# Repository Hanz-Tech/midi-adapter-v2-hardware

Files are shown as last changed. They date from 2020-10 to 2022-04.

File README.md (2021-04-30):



Buy it Here 



[Etsy](https://www.etsy.com/ca/HanzTechInc/listing/979132858/pocket-operator-midi-adapter-v2)

# Disclaimer

You are free to:

Share — copy and redistribute the material in any medium or format

Adapt — remix, transform, and build upon the material

________________________________________

Attribution — You must give appropriate credit, provide a link to the license, and indicate if changes were made. You may do so in any reasonable manner, but not in any way that suggests the licensor endorses you or your use.

NonCommercial — You may not use the material for commercial purposes.

___________________________________________

THE HARDWARE IS PROVIDED "AS IS", WITHOUT WARRANTY OF ANY KIND, EXPRESS OR IMPLIED, INCLUDING BUT NOT LIMITED TO THE WARRANTIES OF MERCHANTABILITY, FITNESS FOR A PARTICULAR PURPOSE AND NONINFRINGEMENT. IN NO EVENT SHALL THE AUTHORS OR COPYRIGHT HOLDERS BE LIABLE FOR ANY CLAIM, DAMAGES OR OTHER LIABILITY, WHETHER IN AN ACTION OF CONTRACT, TORT OR OTHERWISE, ARISING FROM, OUT OF OR IN CONNECTION WITH THE HARDWARE OR THE USE OR OTHER DEALINGS IN THE HARDWARE.

_____________________________________________

# Overview

This repo contains both the CAD for the 3D printed cover for the Pocket Operator and the PCB schematic for the adapter. PCB is created using KiCad. Software can be found [here](https://github.com/PO-MIDI-Adapter/midi-adapter-software/tree/v2)

## For assmebly instruction please go to the [wiki](https://github.com/PO-MIDI-Adapter/midi-adapter-hardware/wiki)

PO-MA (https://www.youtube.com/watch?v=iIQ18DAJAU0 "PO-MA")

# Photos

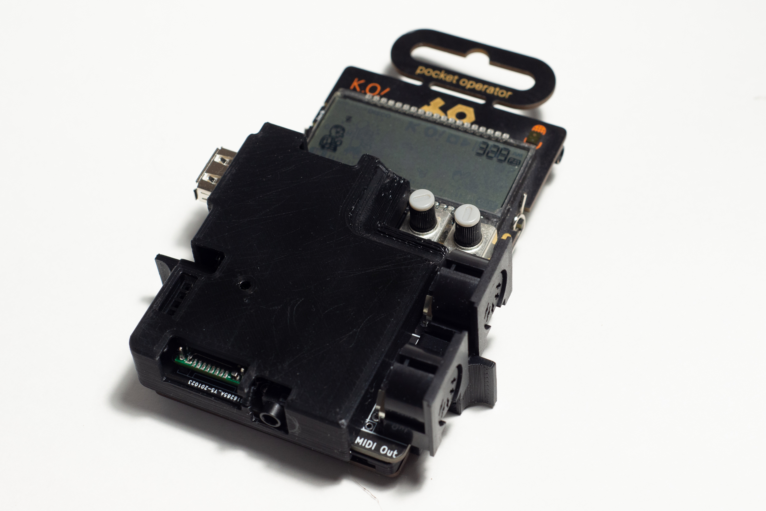
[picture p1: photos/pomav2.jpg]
Cover


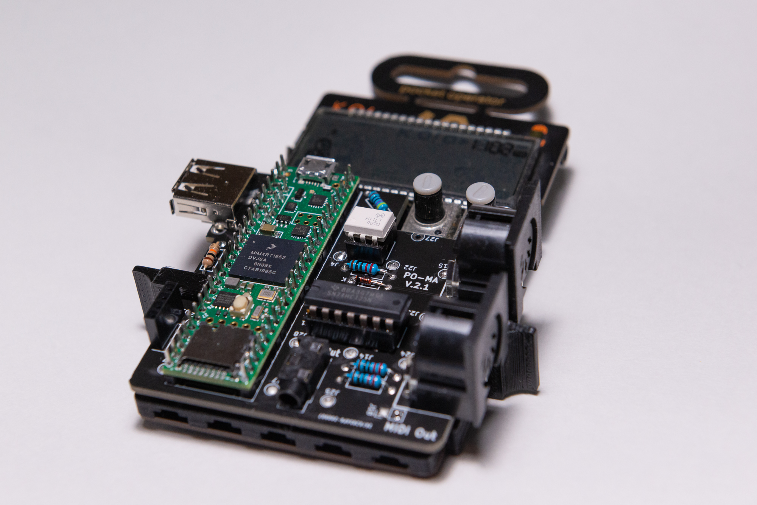
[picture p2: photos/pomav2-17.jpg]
Standalone


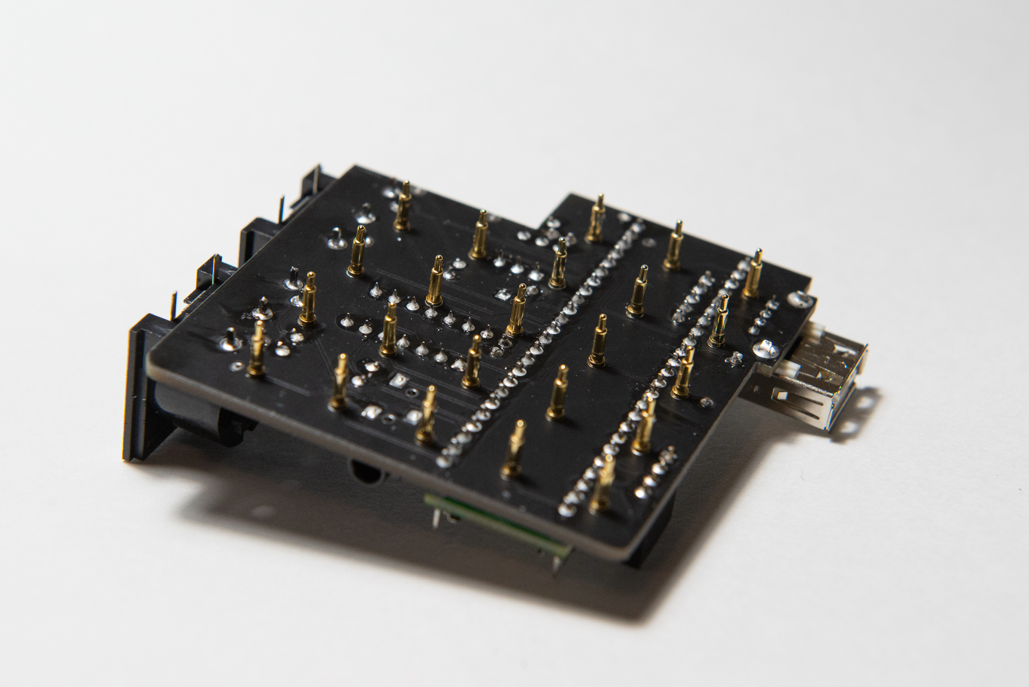
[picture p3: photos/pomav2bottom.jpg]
Pins


With volca and beatstep Setup

With volca and beatstep Setup

Layout

# BOM

1. 1 x PCB board
2. 1 x 3D printed cover (Found in the cad folder)
3. 2 x cover holders  (Found in the cad folder)
4. 25 x pogo pins [ebay](https://www.ebay.ca/itm/100pcs-9mm-Length-Spring-Loaded-Test-Probes-Pogo-Pins-Cusp-Spear-for-Testing/163156710143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)
5. 1 x PJ320B 3.5MM Audio Jack (ebay)

In addition, you would need the following electronics from Digikey (bom.csv)

|Manufacturer Part Number|Manufacturer |Digi-Key Part Number|Quantity|Description |Placement|
|---|---|---|---|---|---|
|SN74HC125N |Texas Instruments |296-1572-5-ND |1 |IC BUFFER NON-INVERT 6V 14DIP |U2
|A 14-LC-TT |Assmann WSW Components |AE9989-ND |1 |CONN IC DIP SOCKET 14POS TIN |U2
|1-2199298-1 |TE Connectivity |A120346-ND |1 |CONN IC DIP SOCKET 6POS TIN |U3
|H11L1M |ON Semiconductors |H11L1-MQT-ND |1 |OPTOISO 4.17KV OPN COLL 6DIP |U3
|PRPC028SACN-RC |Sullins Connector Solutions|S1131EC-28-ND |2 |CONN HEADER VERT 28POS 2.54MM |U1
|DEV-16771 |SparkFun Electronics |1568-DEV-16771-ND |1 |TEENSY 4.1 W/OUT HDRS K66 EVAL  |U1
|SDS-50J |CUI Inc. |CP-2350-ND |2 |CONN RCPT FMALE DIN 5POS SOLDER |J29,J30
|CF14JT220R |Stackpole Electronics Inc  |CF14JT220RCT-ND |3 |RES 220 OHM 1/4W 5% AXIAL |R2,R3,R7
|CF14JT10K0 |Stackpole Electronics Inc  |CF14JT10K0CT-ND |1 |RES 10K OHM 1/4W 5% AXIAL |R4
|CF14JT470R |Stackpole Electronics Inc  |CF14JT470RTR-ND |1 |RES 470 OHM 1/4W 5% AXIAL |R8
|USB-A1HSW6 |On Shore Technology Incs |ED2989-ND |1 |USB-A Receptacle Connector 4 Pos|J19
|C315C104M5U5TA7303 |KEMET |399-9859-1-ND |2 |CAP CER 0.1UF 50V Z5U RADIAL |C2,C1
|PPTC041LFBN-RC |Sullins Connector Solutions|S7002-ND |1 |CONN HDR 4POS 0.1 TIN PCB |J32
|1N914 |ON Semiconductor |1N914FS-ND |1 |DIODE GEN PURP 100V 200MA DO35  |D1

Optional

|Manufacturer Part Number|Manufacturer |Digi-Key Part Number|Quantity  |Description |Placement|
|---|---|---|---|---|---|
|PPTC241LFBN-RC |Sullins Connector Solutions|S7022-ND |2 |CONN HDR 24POS 0.1 TIN PCB |U1

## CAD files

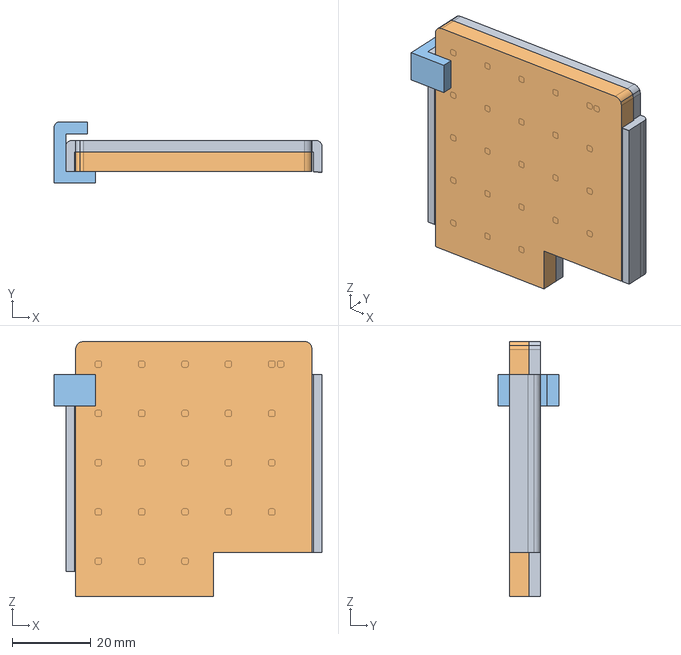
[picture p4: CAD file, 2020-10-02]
cad/f3d/soldering_rig/rig v5.step
68.0 x 15.6 x 64.8 mm

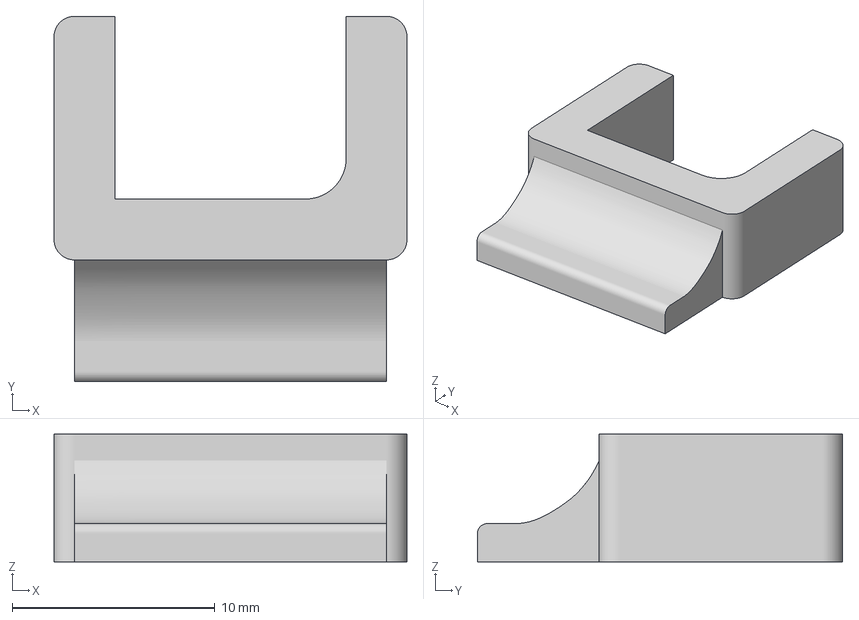
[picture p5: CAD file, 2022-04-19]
cad/stl/cover/holder_v3.3mf
17.4 x 18.0 x 6.30 mm

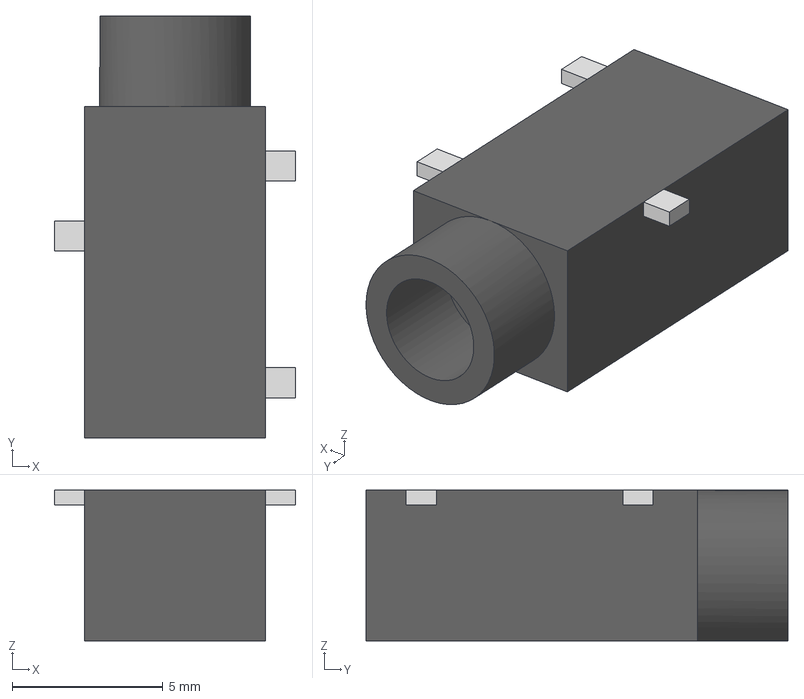
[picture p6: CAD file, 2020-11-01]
cad/stl/soldering_rig/audio_jack v2.step
8.00 x 14.0 x 5.00 mm

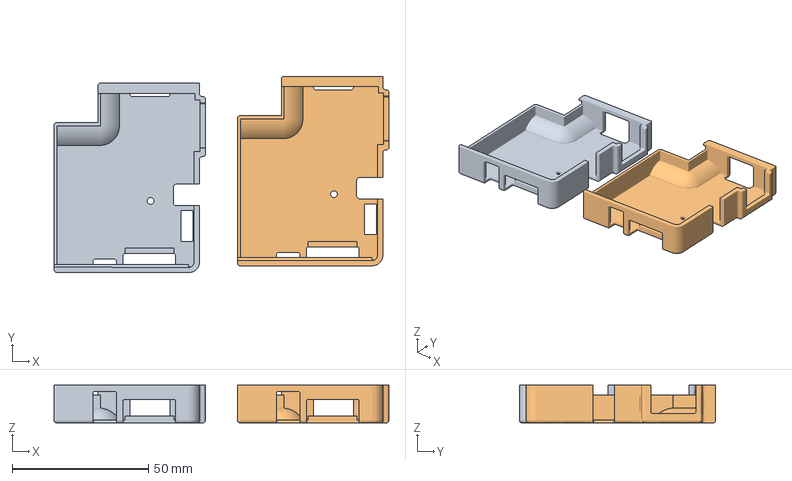
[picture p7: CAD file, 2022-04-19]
cad/stl/cover/shield.3mf
122.9 x 72.1 x 13.9 mm

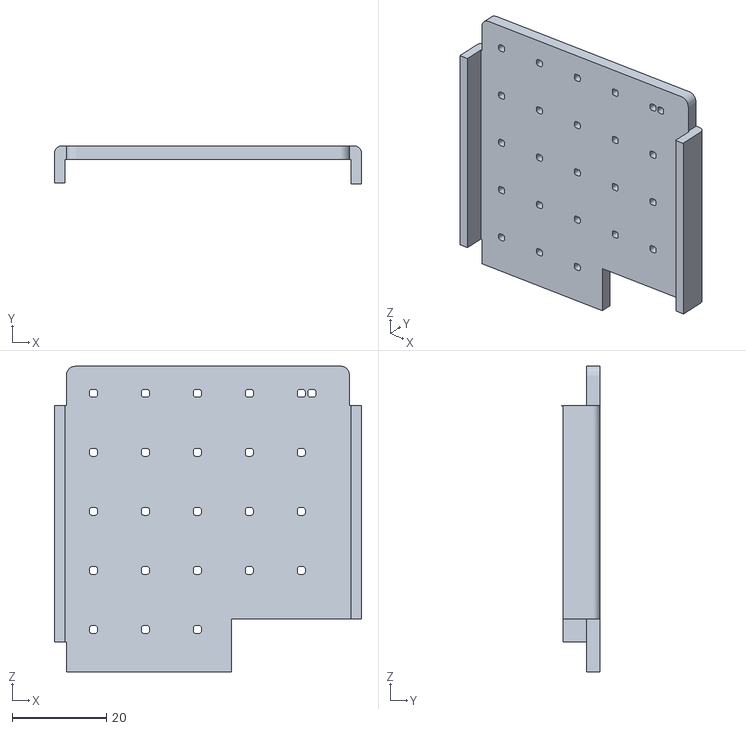
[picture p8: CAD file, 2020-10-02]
cad/stl/soldering_rig/top.stl
65.0 x 8.06 x 64.8

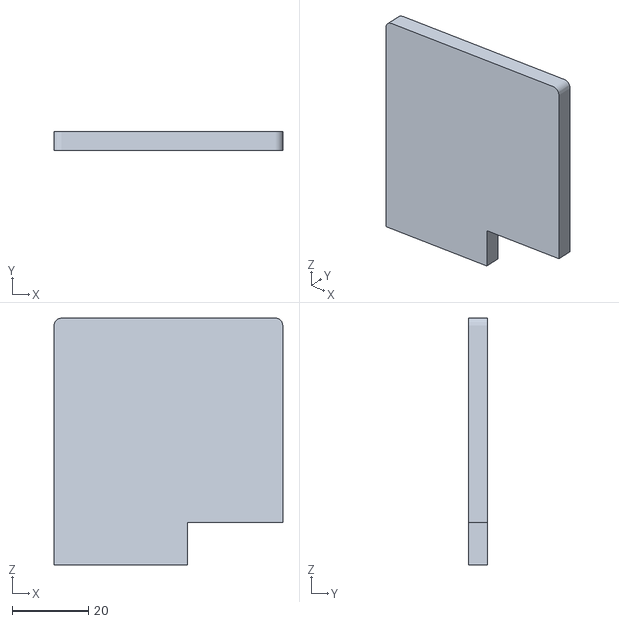
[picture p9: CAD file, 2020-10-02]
cad/stl/soldering_rig/bottom.stl
60.0 x 4.95 x 64.8

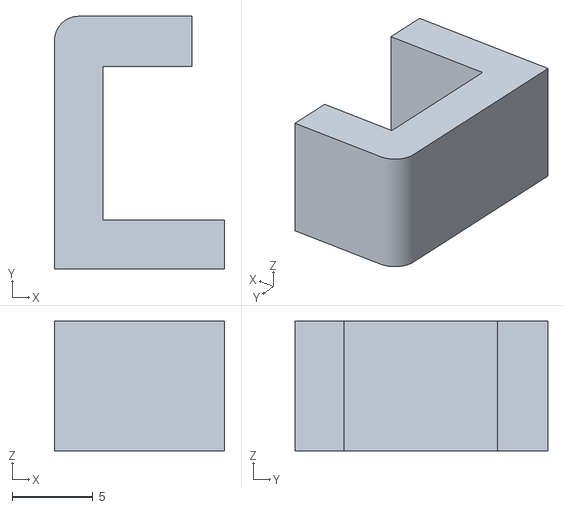
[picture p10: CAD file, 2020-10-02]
cad/stl/soldering_rig/holder.stl
10.5 x 15.6 x 8.00

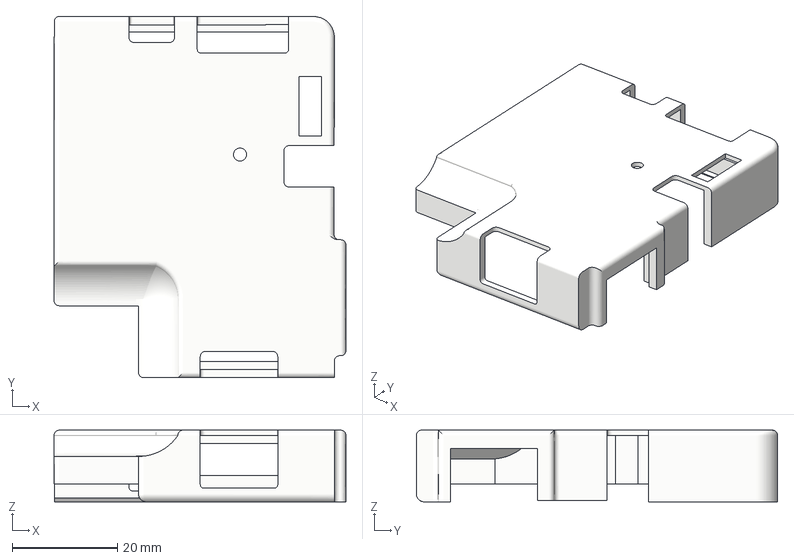
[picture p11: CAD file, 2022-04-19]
cad/stl/cover/shield_rev_2.3mf
55.6 x 68.8 x 13.7 mm

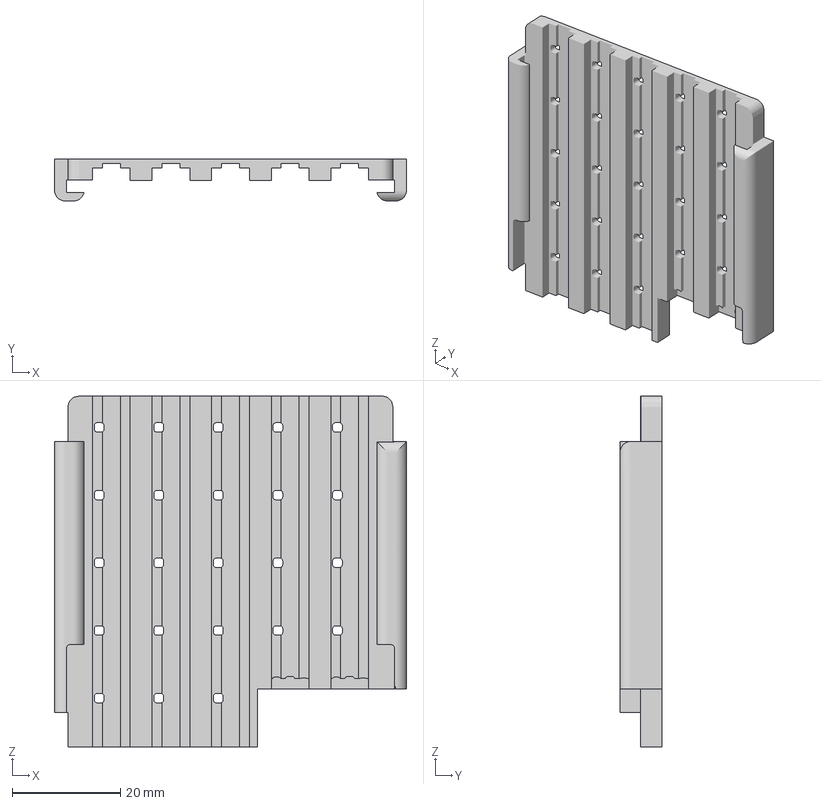
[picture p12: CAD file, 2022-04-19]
cad/stl/cover/cover_v2_3.3mf
65.0 x 7.75 x 64.8 mm

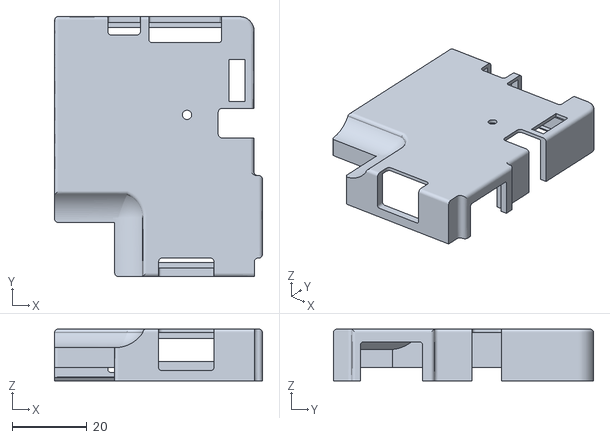
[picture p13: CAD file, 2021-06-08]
cad/stl/cover/shield_v2.stl
55.6 x 69.6 x 13.9

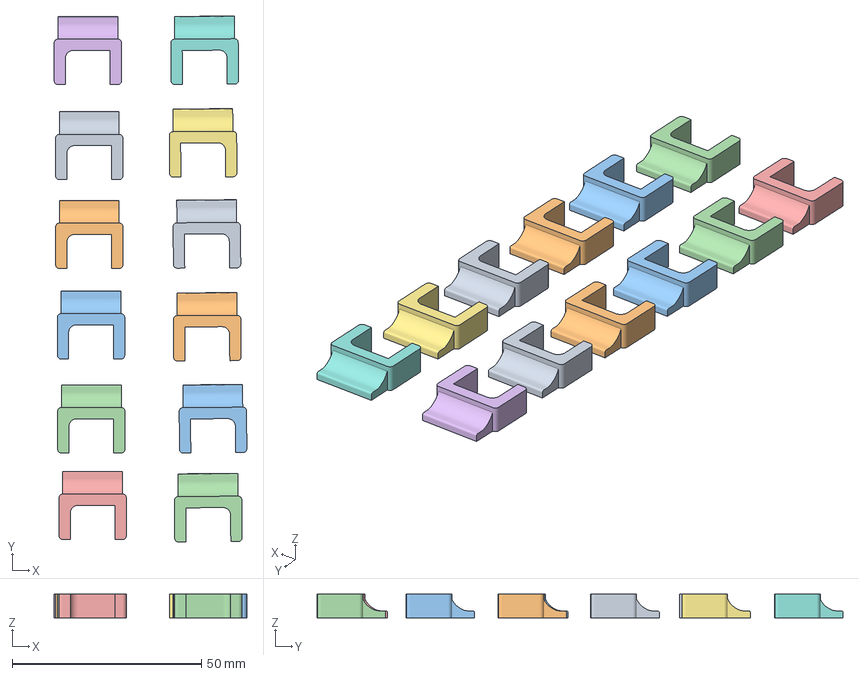
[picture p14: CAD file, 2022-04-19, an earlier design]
cad/stl/cover/holder_v2.3mf
50.9 x 138.9 x 6.30 mm
holder_v2.stl x 2

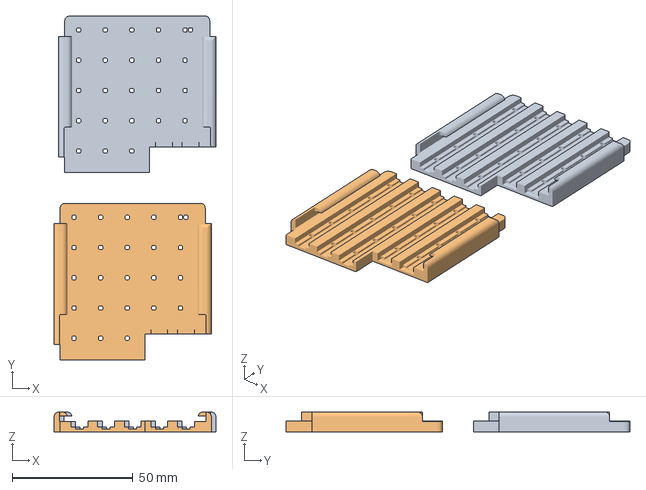
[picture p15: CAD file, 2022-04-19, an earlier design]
cad/stl/cover/cover_v2_1.3mf
66.9 x 142.2 x 8.25 mm

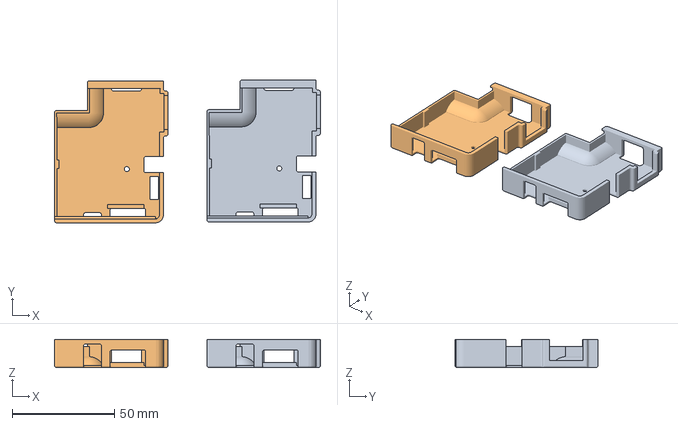
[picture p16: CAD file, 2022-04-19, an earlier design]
cad/stl/cover/shield_rev_1.3mf
130.3 x 69.9 x 13.9 mm

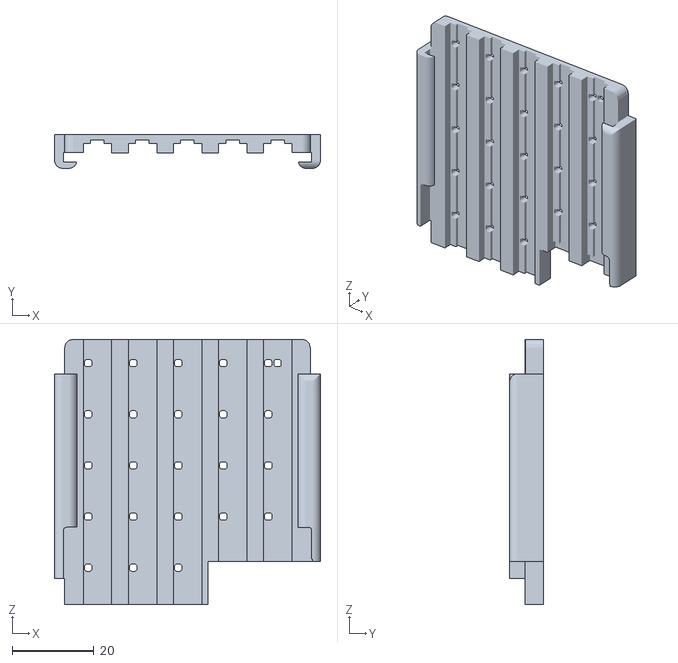
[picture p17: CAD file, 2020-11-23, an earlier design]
cad/stl/cover/cover_v2.stl
65.0 x 8.25 x 64.8

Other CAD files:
cad/stl/cover/cover_v2_2.3mf
cad/f3d/cover/holder v3.f3d
cad/stl/cover/cover_v2_1.stl
cad/stl/cover/holder_v2.stl

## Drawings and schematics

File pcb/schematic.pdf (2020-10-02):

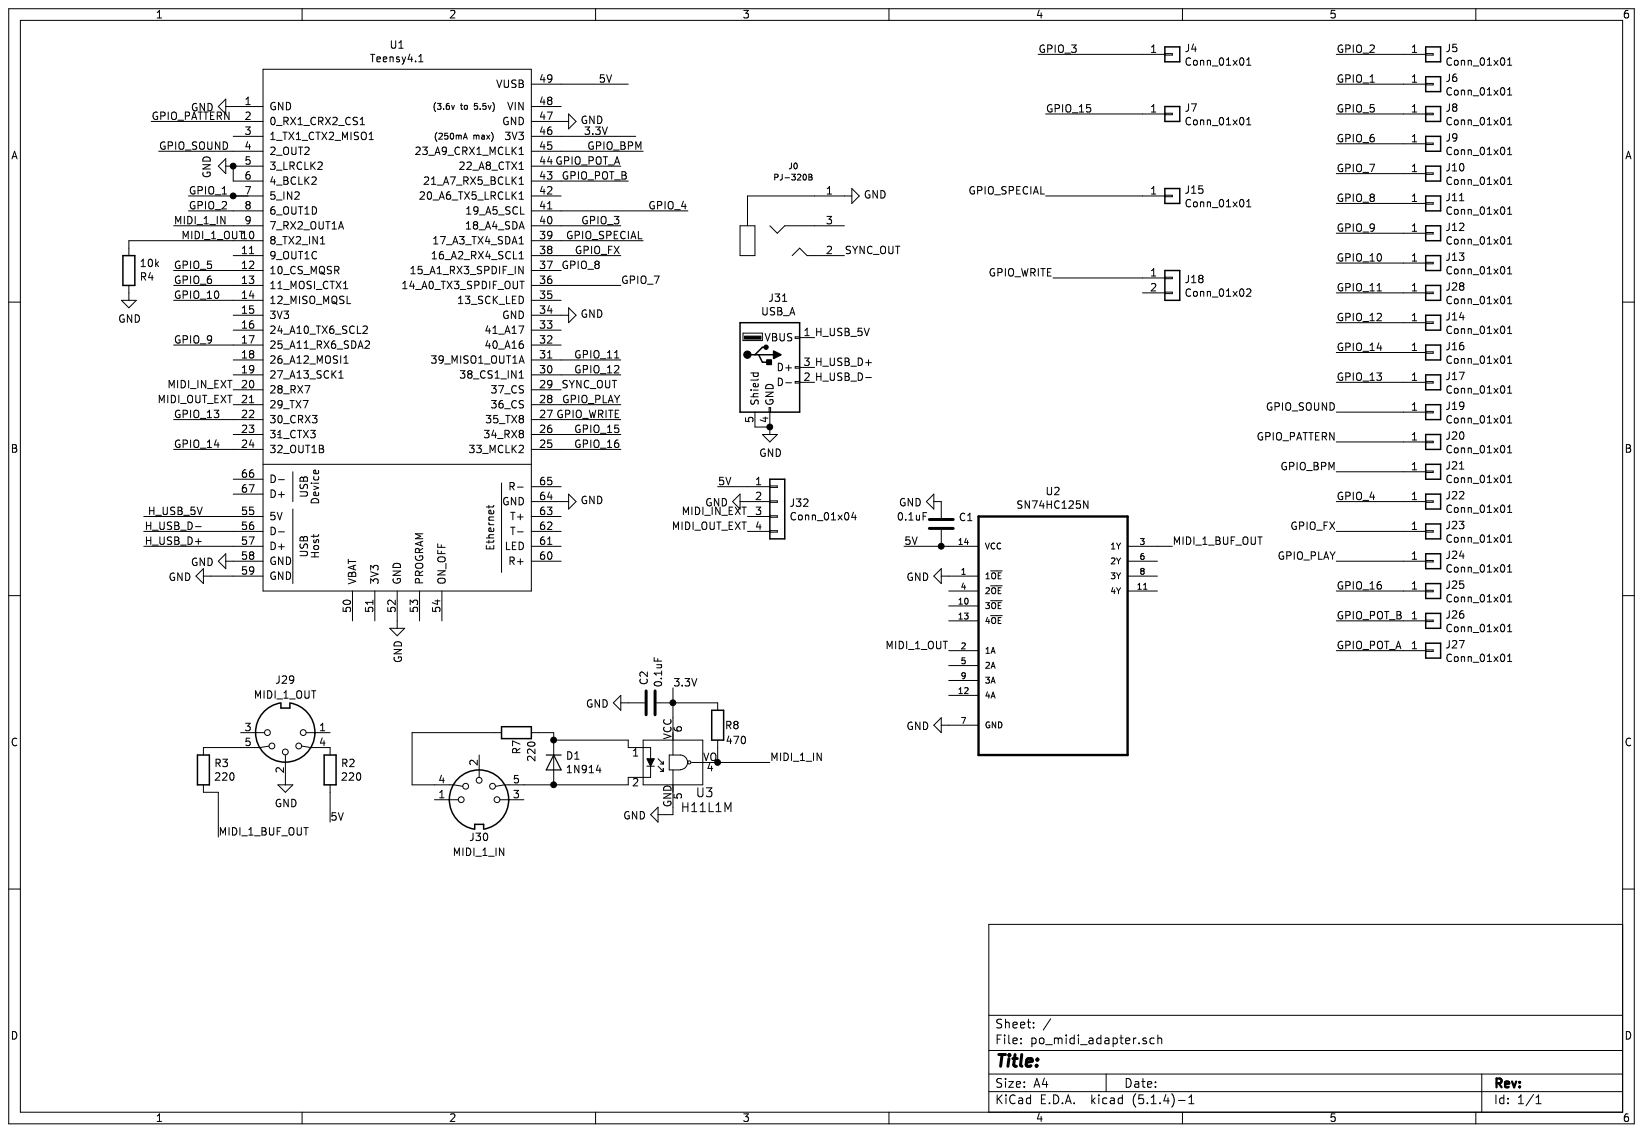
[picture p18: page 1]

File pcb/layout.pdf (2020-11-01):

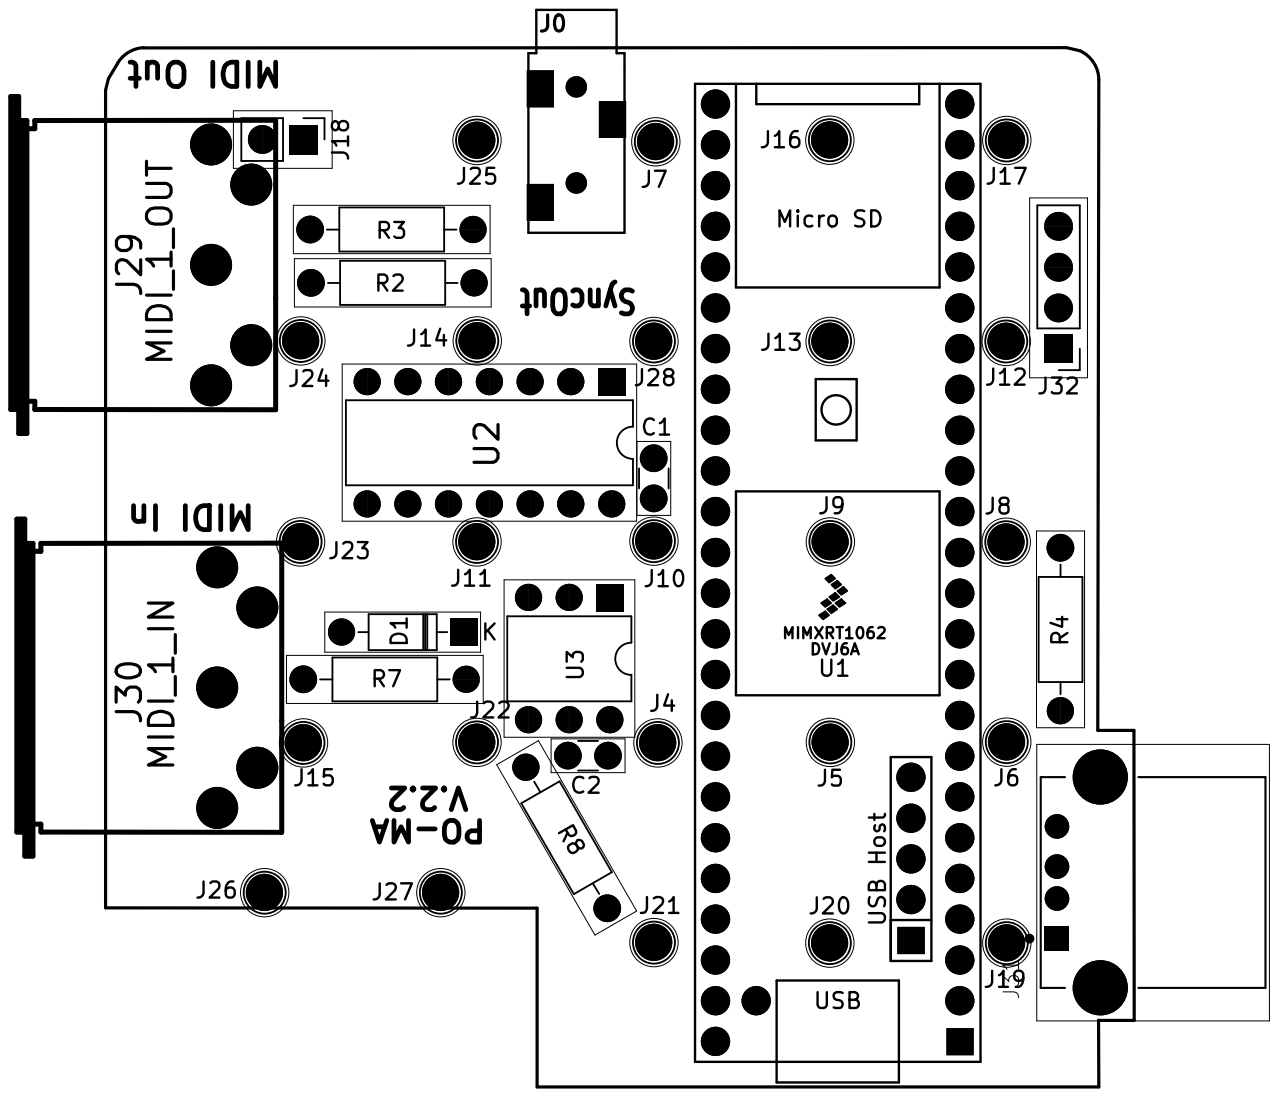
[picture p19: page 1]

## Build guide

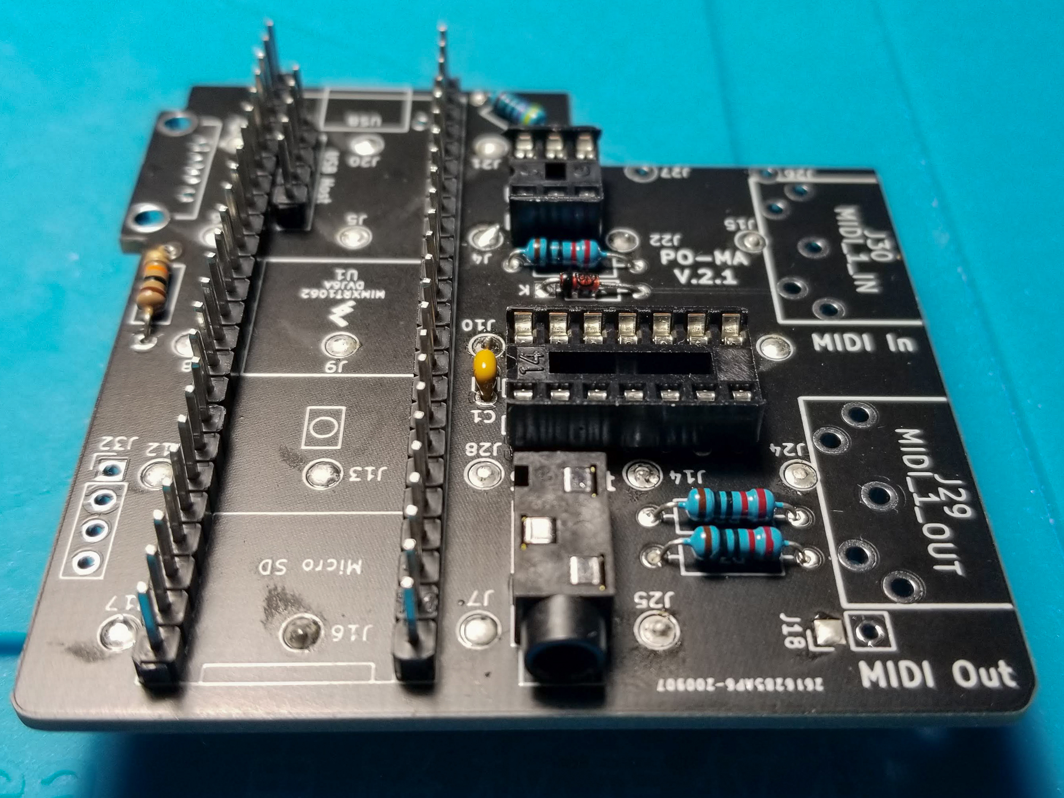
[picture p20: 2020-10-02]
photos/assembly/010.jpg

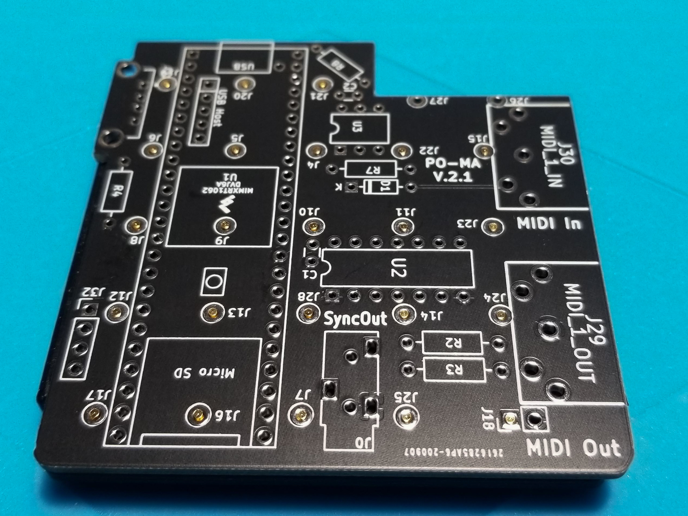
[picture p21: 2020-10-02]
photos/assembly/02.jpg

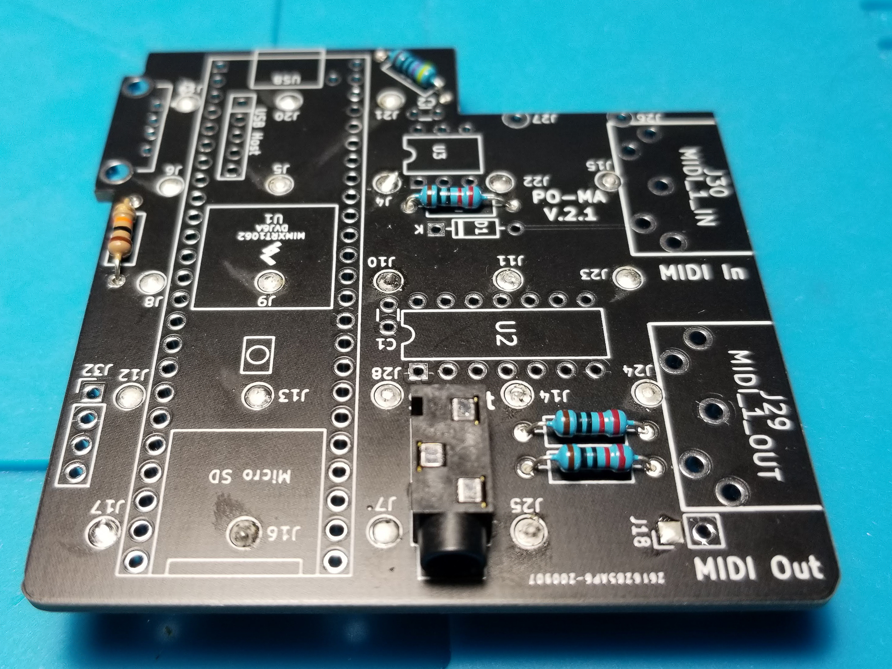
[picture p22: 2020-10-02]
photos/assembly/07.jpg

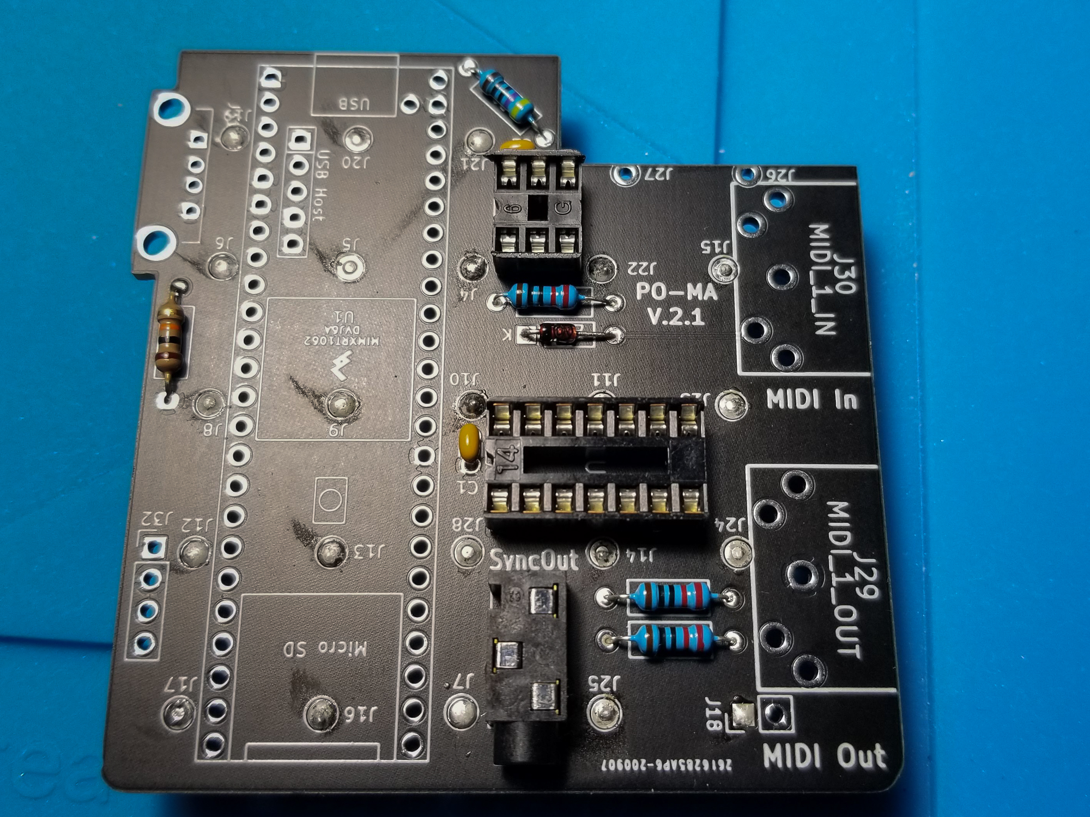
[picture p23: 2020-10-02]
photos/assembly/09.jpg

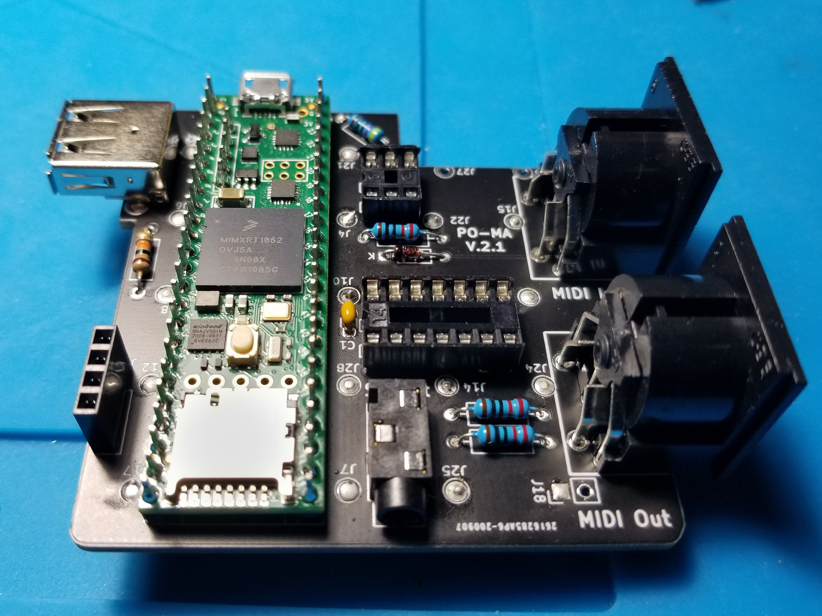
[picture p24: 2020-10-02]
photos/assembly/013.jpg

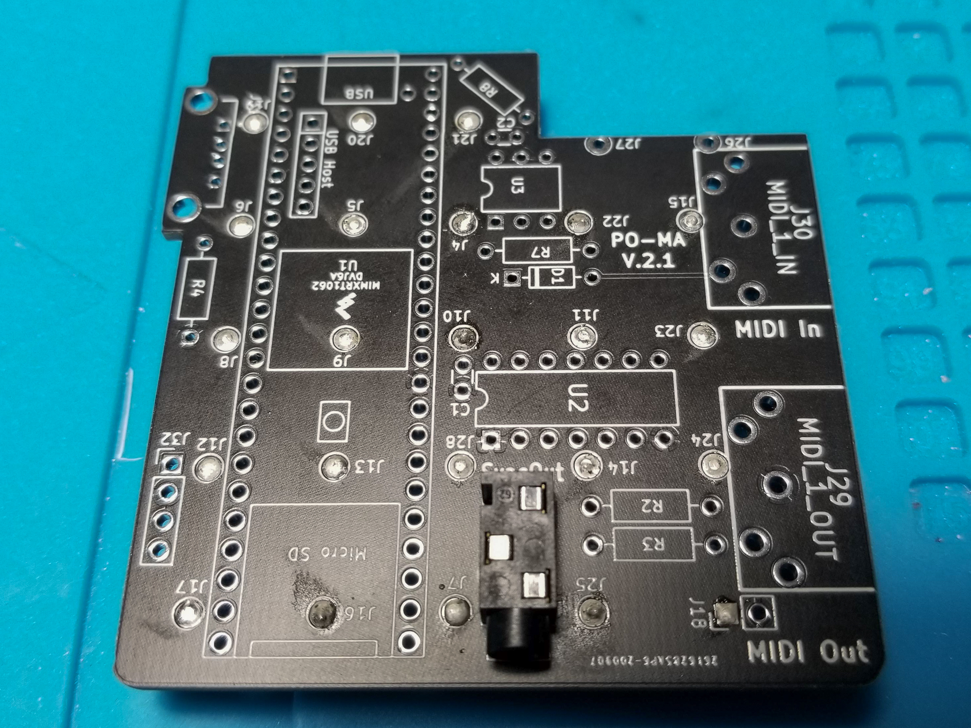
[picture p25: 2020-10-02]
photos/assembly/06.jpg

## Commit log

2020-10-02 initial push
    [bottom.stl, cover.stl, holder v3.f3d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]
2020-10-02 added bom in csv
    [v2_bom.csv]
2020-10-09 updated bom and photos
    [v2_bom.csv]
2020-11-23 updated photos
    [cover.stl, cover_v2.stl, holder v3.stl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]
2020-12-25 updated stl for case
    [cover_v2_1.stl]
2021-06-08 added new cad
    [cover_v2_1.3mf, shield.3mf, shield_v2.stl]
2022-04-19 updated cover stl
    [cover_v2_1.3mf, cover_v2_2.3mf, cover_v2_3.3mf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]

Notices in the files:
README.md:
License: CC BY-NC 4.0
